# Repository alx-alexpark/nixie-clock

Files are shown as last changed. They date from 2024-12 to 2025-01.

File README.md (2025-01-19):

# ИН-12 Nixie Tube Clock

clock

A nixie tube clock made using ИН-12 (IN-12) tubes. Uses k155id1 drivers and a boost converter made using [this reference design](https://github.com/drkmsmithjr/NixiePowerSupply). Time is synchronized over WiFi using NTP (<1sec inaccuracy), and all firmware is written using CircuitPython.

Read more at https://parkalex.dev/posts/nixieclock

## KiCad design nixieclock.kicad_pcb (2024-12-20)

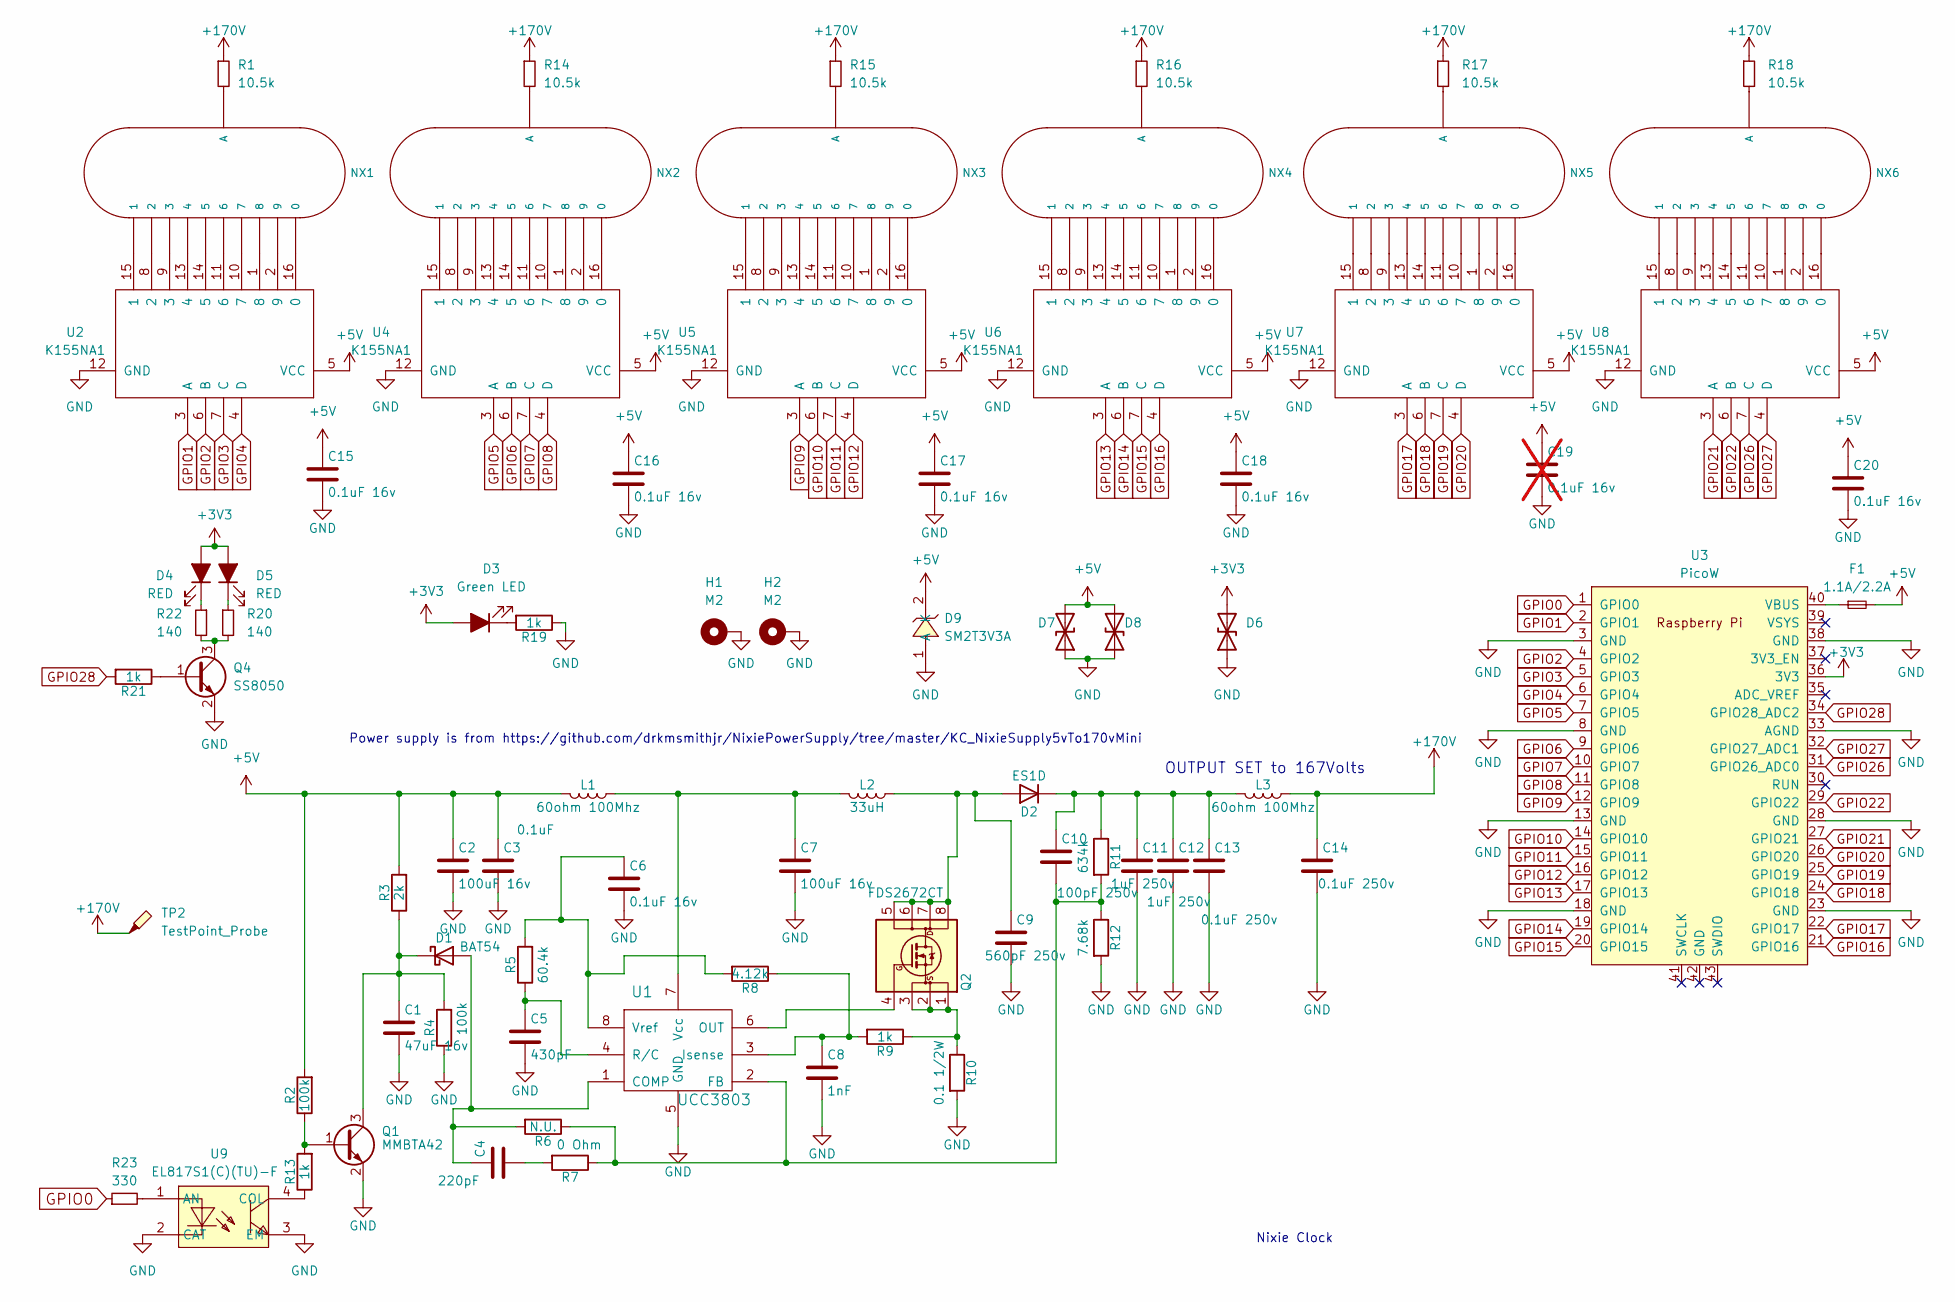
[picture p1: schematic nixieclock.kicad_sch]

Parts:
C1: 47uF 16v; C_1210_3225Metric_Pad1.33x2.70mm_HandSolder; LCSC Part C77101
C2, C7: 100uF 16v; C_1210_3225Metric_Pad1.33x2.70mm_HandSolder; LCSC Part C7432790
C3: 0.1uF; C_0603_1608Metric_Pad1.08x0.95mm_HandSolder; LCSC Part C14663
C4: 220pF; C_0402_1005Metric_Pad0.74x0.62mm_HandSolder; LCSC Part C1530
C5: 430pF; C_0805_2012Metric_Pad1.18x1.45mm_HandSolder; LCSC Part C67898
C6, C15, C16, C17, C18, C20: 0.1uF 16v; C_0603_1608Metric_Pad1.08x0.95mm_HandSolder; LCSC Part C14663
C8: 1nF; C_0603_1608Metric_Pad1.08x0.95mm_HandSolder; LCSC Part C100040
C9: 560pF 250v; C_0805_2012Metric_Pad1.18x1.45mm_HandSolder; LCSC Part C576987
C10: 100pF 250v; C_0805_2012Metric_Pad1.18x1.45mm_HandSolder; LCSC Part C5186766
C11, C12: 1uF 250v; C_1812_4532Metric_Pad1.57x3.40mm_HandSolder; LCSC Part C381468
C13, C14: 0.1uF 250v; C_0805_2012Metric_Pad1.18x1.45mm_HandSolder; LCSC Part C5182461
C19: 0.1uF 16v; C_0603_1608Metric_Pad1.08x0.95mm_HandSolder; LCSC Part C14663; not fitted
D1: BAT54; D_SOD-323_HandSoldering; MPN BAT54WS-7-F; LCSC Part C124205
D2: ES1D; D_SMA_Handsoldering; MPN ES1D; LCSC Part C84602
D3: Green LED; LED_0805_2012Metric_Pad1.15x1.40mm_HandSolder; LCSC Part C2297
D4, D5: RED; LED_0805_2012Metric_Pad1.15x1.40mm_HandSolder; LCSC Part C84256
D6, D7, D8: PESD5V5C1BLYL; D_SOD-882; MPN PESD5V5C1BLYL
D9: SM2T3V3A; DO-216AA_L1.9-W1.9-LS3.8-FD; LCSC Part C970557
F1: 1.1A/2.2A; Fuse_1812_4532Metric_Pad1.30x3.40mm_HandSolder; MPN MF-MSMF110-2
H1, H2: M2; MountingHole_2.2mm_M2_DIN965_Pad_TopBottom
L1, L3: 60ohm 100Mhz; L_0805_2012Metric_Pad1.05x1.20mm_HandSolder; MPN MH2029-600Y
L2: 33uH; WE-PD_1210; MPN 7447709330
NX1, NX2, NX3, NX4, NX5, NX6: IN-12A; nixies-us-IN-12-DSUB
Q1: MMBTA42; SOT-23_Handsoldering; LCSC Part C118745
Q2: FDS2672CT; SOIC-8_3.9x4.9mm_P1.27mm; MPN FDS2672CT-ND
Q4: SS8050; SOT-23
R1, R14, R15, R16, R17, R18: 10.5k; R_0805_2012Metric_Pad1.20x1.40mm_HandSolder; LCSC Part C2093736
R2, R4: 100k; R_0603_1608Metric_Pad0.98x0.95mm_HandSolder; LCSC Part C14675
R3: 2k; R_0603_1608Metric_Pad0.98x0.95mm_HandSolder; LCSC Part C22975
R5: 60.4k; R_0603_1608Metric_Pad0.98x0.95mm_HandSolder; LCSC Part C23089
R6: N.U.
R7: 0 Ohm; R_0603_1608Metric_Pad0.98x0.95mm_HandSolder; LCSC Part C21189
R8: 4.12k; R_0603_1608Metric_Pad0.98x0.95mm_HandSolder; LCSC Part C2960702
R9, R13, R19, R21: 1k; R_0603_1608Metric_Pad0.98x0.95mm_HandSolder; LCSC Part C21190
R10: 0.1 1/2W; C_1210_3225Metric_Pad1.33x2.70mm_HandSolder; LCSC Part C2974119
R11: 634k; R_1206_3216Metric_Pad1.30x1.75mm_HandSolder; LCSC Part C3037408
R12: 7.68k; R_1206_3216Metric_Pad1.30x1.75mm_HandSolder; LCSC Part C3037264
R20, R22: 140; R_0603_1608Metric_Pad0.98x0.95mm_HandSolder; LCSC Part C2974027
R23: 330; R_0603_1608Metric_Pad0.98x0.95mm_HandSolder; LCSC Part C23138
TP2: TestPoint_Probe; TestPoint_Loop_D2.54mm_Drill1.5mm_Beaded
U1: UCC3803; SOIC-8_3.9x4.9mm_P1.27mm; LCSC Part C2657971
U2, U4, U5, U6, U7, U8: K155NA1; DIP-16_W7.62mm_LongPads
U3: PicoW; RPi_PicoW_SMD_TH
U9: EL817S1(C)(TU)-F; OPTO-SMD-4_L4.6-W6.5-P2.54-LS10.3-TL; LCSC Part C106900

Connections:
+3V3: D3.2 (A), D4.2 (A), D5.2 (A), D6.2 (A2), U3.36 (3V3)
+5V: C2.1, C3.1, C15.1, C16.1, C17.1, C18.1, C19.1, C20.1, D7.2 (A2), D8.2 (A2), D9.2 (K), F1.2, L1.2, R2.2, R3.2, U2.5 (VCC), U4.5 (VCC), U5.5 (VCC), U6.5 (VCC), U7.5 (VCC), U8.5 (VCC)
+170V: C14.1, L3.1, R1.1, R14.1, R15.1, R16.1, R17.1, R18.1, TP2.1
GND: C1.2, C2.2, C3.2, C5.2, C6.2, C7.2, C8.2, C9.2, C11.2, C12.2, C13.2, C14.2, C15.2, C16.2, C17.2, C18.2, C19.2, C20.2, D6.1 (A1), D7.1 (A1), D8.1 (A1), D9.1 (A), H1.1, H2.1, Q1.2 (E), Q4.2 (E), R4.1, R10.2, R12.2, R19.1, U1.5 (GND), U2.12 (GND), U3.3 (GND), U3.8 (GND), U3.13 (GND), U3.18 (GND), U3.23 (GND), U3.28 (GND), U3.33 (AGND), U3.38 (GND), U4.12 (GND), U5.12 (GND), U6.12 (GND), U7.12 (GND), U8.12 (GND), U9.2 (CAT), U9.3 (EM)
GPIO0: R23.1, U3.1 (GPIO0)
GPIO1: U2.3 (A), U3.2 (GPIO1)
GPIO2: U2.6 (B), U3.4 (GPIO2)
GPIO3: U2.7 (C), U3.5 (GPIO3)
GPIO4: U2.4 (D), U3.6 (GPIO4)
GPIO5: U3.7 (GPIO5), U4.3 (A)
GPIO6: U3.9 (GPIO6), U4.6 (B)
GPIO7: U3.10 (GPIO7), U4.7 (C)
GPIO8: U3.11 (GPIO8), U4.4 (D)
GPIO9: U3.12 (GPIO9), U5.3 (A)
GPIO10: U3.14 (GPIO10), U5.6 (B)
GPIO11: U3.15 (GPIO11), U5.7 (C)
GPIO12: U3.16 (GPIO12), U5.4 (D)
GPIO13: U3.17 (GPIO13), U6.3 (A)
GPIO14: U3.19 (GPIO14), U6.6 (B)
GPIO15: U3.20 (GPIO15), U6.7 (C)
GPIO16: U3.21 (GPIO16), U6.4 (D)
GPIO17: U3.22 (GPIO17), U7.3 (A)
GPIO18: U3.24 (GPIO18), U7.6 (B)
GPIO19: U3.25 (GPIO19), U7.7 (C)
GPIO20: U3.26 (GPIO20), U7.4 (D)
GPIO21: U3.27 (GPIO21), U8.3 (A)
GPIO22: U3.29 (GPIO22), U8.6 (B)
GPIO26: U3.31 (GPIO26_ADC0), U8.7 (C)
GPIO27: U3.32 (GPIO27_ADC1), U8.4 (D)
GPIO28: R21.2, U3.34 (GPIO28_ADC2)
unnamed: C4.2, R7.2
unnamed: C4.1, D1.2 (A), R6.2, U1.1 (COMP)
unnamed: C1.1, D1.1 (K), Q1.3 (C), R3.1, R4.2
unnamed: C9.1, D2.2 (A), L2.1, Q2.5 (D), Q2.6 (D), Q2.7 (D), Q2.8 (D)
unnamed: C10.1, C11.1, C12.1, C13.1, D2.1 (K), L3.2, R11.1
unnamed: D3.1 (K), R19.2
unnamed: D4.1 (K), R22.1
unnamed: D5.1 (K), R20.1
unnamed: NX1.A, R1.2
unnamed: NX2.A, R14.2
unnamed: NX3.A, R15.2
unnamed: NX4.A, R16.2
unnamed: NX5.A, R17.2
unnamed: NX6.A, R18.2
unnamed: Q1.1 (B), R2.1, R13.2
unnamed: Q2.4 (G), U1.6 (OUT)
unnamed: Q2.1 (S), Q2.2 (S), Q2.3 (S), R9.1, R10.1
unnamed: Q4.1 (B), R21.1
unnamed: Q4.3 (C), R20.2, R22.2
unnamed: C10.2, R6.1, R7.1, R11.2, R12.1, U1.2 (FB)
unnamed: C8.1, R8.1, R9.2, U1.3 (Isense)
unnamed: C5.1, R5.1, U1.4 (R/C)
unnamed: C7.1, L1.1, L2.2, U1.7 (Vcc)
unnamed: C6.1, R5.2, R8.2, U1.8 (Vref)
unnamed: NX1.0, U2.16 (0)
unnamed: NX1.1, U2.15 (1)
unnamed: NX1.2, U2.8 (2)
unnamed: NX1.3, U2.9 (3)
unnamed: NX1.4, U2.13 (4)
unnamed: NX1.5, U2.14 (5)
unnamed: NX1.6, U2.11 (6)
unnamed: NX1.7, U2.10 (7)
unnamed: NX1.8, U2.1 (8)
unnamed: NX1.9, U2.2 (9)
unnamed: F1.1, U3.40 (VBUS)
unnamed: NX2.0, U4.16 (0)
unnamed: NX2.1, U4.15 (1)
unnamed: NX2.2, U4.8 (2)
unnamed: NX2.3, U4.9 (3)
unnamed: NX2.4, U4.13 (4)
unnamed: NX2.5, U4.14 (5)
unnamed: NX2.6, U4.11 (6)
unnamed: NX2.7, U4.10 (7)
unnamed: NX2.8, U4.1 (8)
unnamed: NX2.9, U4.2 (9)
unnamed: NX3.0, U5.16 (0)
unnamed: NX3.1, U5.15 (1)
unnamed: NX3.2, U5.8 (2)
unnamed: NX3.3, U5.9 (3)
unnamed: NX3.4, U5.13 (4)
unnamed: NX3.5, U5.14 (5)
unnamed: NX3.6, U5.11 (6)
unnamed: NX3.7, U5.10 (7)
unnamed: NX3.8, U5.1 (8)
unnamed: NX3.9, U5.2 (9)
unnamed: NX4.0, U6.16 (0)
unnamed: NX4.1, U6.15 (1)
unnamed: NX4.2, U6.8 (2)
unnamed: NX4.3, U6.9 (3)
unnamed: NX4.4, U6.13 (4)
unnamed: NX4.5, U6.14 (5)
unnamed: NX4.6, U6.11 (6)
unnamed: NX4.7, U6.10 (7)
unnamed: NX4.8, U6.1 (8)
unnamed: NX4.9, U6.2 (9)
unnamed: NX5.0, U7.16 (0)
unnamed: NX5.1, U7.15 (1)
unnamed: NX5.2, U7.8 (2)
unnamed: NX5.3, U7.9 (3)
unnamed: NX5.4, U7.13 (4)
unnamed: NX5.5, U7.14 (5)
unnamed: NX5.6, U7.11 (6)
unnamed: NX5.7, U7.10 (7)
unnamed: NX5.8, U7.1 (8)
unnamed: NX5.9, U7.2 (9)
unnamed: NX6.0, U8.16 (0)
unnamed: NX6.1, U8.15 (1)
unnamed: NX6.2, U8.8 (2)
unnamed: NX6.3, U8.9 (3)
unnamed: NX6.4, U8.13 (4)
unnamed: NX6.5, U8.14 (5)
unnamed: NX6.6, U8.11 (6)
unnamed: NX6.7, U8.10 (7)
unnamed: NX6.8, U8.1 (8)
unnamed: NX6.9, U8.2 (9)
unnamed: R23.2, U9.1 (AN)
unnamed: R13.1, U9.4 (COL)

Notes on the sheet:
Power supply is from https://github.com/drkmsmithjr/NixiePowerSupply/tree/master/KC_NixieSupply5vTo170vMini
Nixie Clock
OUTPUT SET to 167Volts

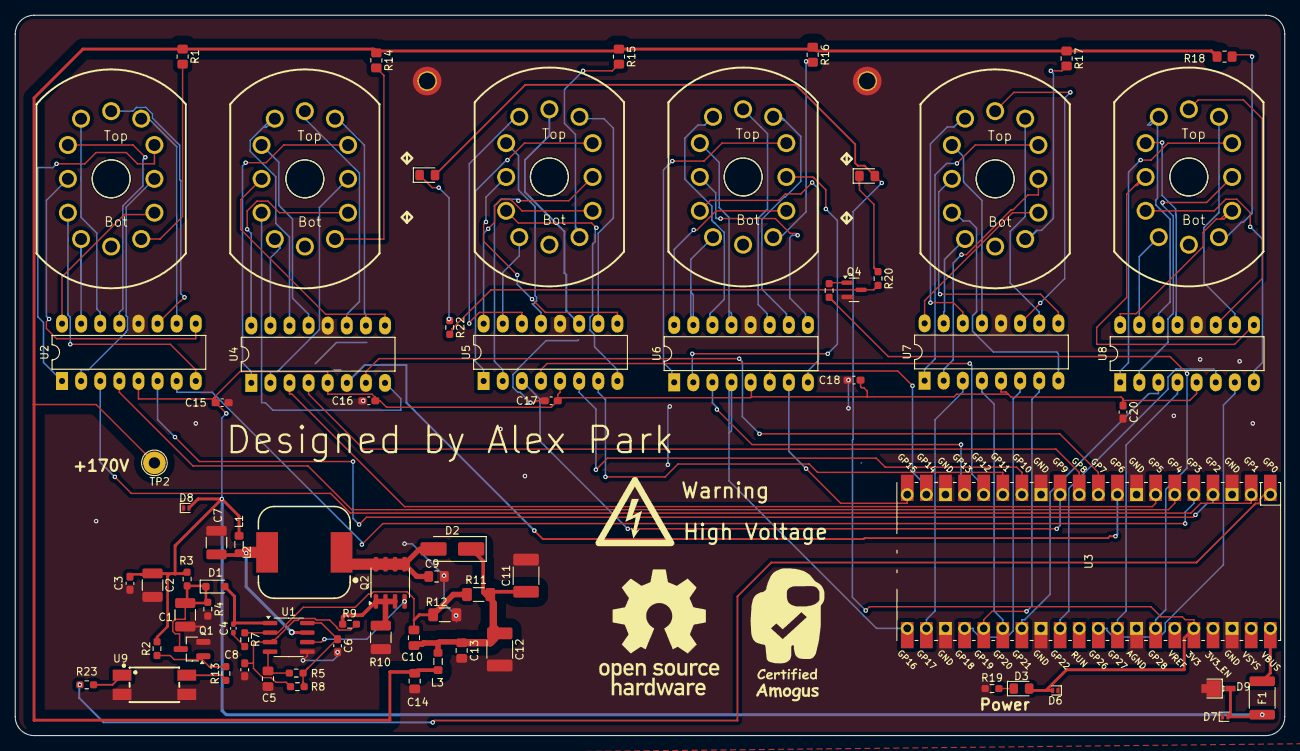
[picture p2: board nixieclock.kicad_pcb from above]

Board: 2 copper layers, 168.8 x 95.8 mm, 75 parts (0 on the bottom side), 117 nets.

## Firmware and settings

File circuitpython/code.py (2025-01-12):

import digitalio
import board

import os
import time

import rtc
import socketpool
import wifi

import adafruit_ntp

HVenable = digitalio.DigitalInOut(board.GP0)
HVenable.direction = digitalio.Direction.OUTPUT

led = digitalio.DigitalInOut(board.GP28)
led.direction = digitalio.Direction.OUTPUT


class NixieTube:
    def __init__(self, pin1, pin2, pin3, pin4):
        self.c1 = digitalio.DigitalInOut(pin1)
        self.c1.direction = digitalio.Direction.OUTPUT
        self.c2 = digitalio.DigitalInOut(pin2)
        self.c2.direction = digitalio.Direction.OUTPUT
        self.c3 = digitalio.DigitalInOut(pin3)
        self.c3.direction = digitalio.Direction.OUTPUT
        self.c4 = digitalio.DigitalInOut(pin4)
        self.c4.direction = digitalio.Direction.OUTPUT
        
        self.c1.value = True
        self.c2.value = True
        self.c3.value = True
        self.c4.value = True

    def display_digit(self, digit):
        # Convert the digit to a 4-bit binary representation
        binary_representation = '{0:04b}'.format(digit)
        print(binary_representation)
        self.c1.value = bool(int(binary_representation[3]))
        self.c2.value = bool(int(binary_representation[2]))
        self.c3.value = bool(int(binary_representation[1]))
        self.c4.value = bool(int(binary_representation[0 ]))


    def clear(self):
        """
        Turn off all segments of the Nixie tube.
        """
        self.c1.value = True
        self.c2.value = True
        self.c3.value = True
        self.c4.value = True
    
nixie1 = NixieTube(board.GP1, board.GP2, board.GP3, board.GP4)
nixie2 = NixieTube(board.GP5, board.GP6, board.GP7, board.GP8)
nixie3 = NixieTube(board.GP9, board.GP10, board.GP11, board.GP12)
nixie4 = NixieTube(board.GP13, board.GP14, board.GP15, board.GP16)
nixie5 = NixieTube(board.GP17, board.GP18, board.GP19, board.GP20)
nixie6 = NixieTube(board.GP21, board.GP22, board.GP26, board.GP27)

wifi_ssid = os.getenv("CIRCUITPY_WIFI_SSID")
wifi_password = os.getenv("CIRCUITPY_WIFI_PASSWORD")
if wifi_ssid is None:
    print("WiFi credentials are kept in settings.toml, please add them there!")
    raise ValueError("SSID not found in environment variables")

try:
    wifi.radio.connect(wifi_ssid, wifi_password)
except ConnectionError:
    print("Failed to connect to WiFi with provided credentials")
    raise

pool = socketpool.SocketPool(wifi.radio)
ntp = adafruit_ntp.NTP(pool, tz_offset=-6, cache_seconds=3600)

rtc.RTC().datetime = ntp.datetime

HVenable.value = True

# After getting the time, do a quick cycle of all the digits to reveal any problems
for digit in range(10):
    led.value = not led.value
    nixie1.display_digit(digit)
    nixie2.display_digit(digit)
    nixie3.display_digit(digit)
    nixie4.display_digit(digit)
    nixie5.display_digit(digit)
    nixie6.display_digit(digit)
    time.sleep(0.3)  
    
nixie1.clear()  
nixie2.clear()
nixie3.clear()
nixie4.clear()
nixie5.clear()
nixie6.clear()

while True:
    print(time.localtime())
    timel = time.localtime()
    
    hour = "{:02}".format(timel.tm_hour)
    min = "{:02}".format(timel.tm_min)
    sec = "{:02}".format(timel.tm_sec)
    
    if timel.tm_sec % 2 == 0:
        led.value = True
    else:
        led.value = False
        
    nixie1.display_digit(int(hour[0]))
    nixie2.display_digit(int(hour[1]))
    nixie3.display_digit(int(min[0]))
    nixie4.display_digit(int(min[1]))
    nixie5.display_digit(int(sec[0]))
    nixie6.display_digit(int(sec[1]))
    
    time.sleep(0.01)

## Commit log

2024-12-15 things happened
    [nixieclock.kicad_pcb, nixieclock.kicad_sch]
2024-12-15 schematic mostly done, started laying out board
    [nixieclock.kicad_pcb, nixieclock.kicad_sch]
2024-12-15 mostly done i guess?
    [nixieclock.kicad_pcb, nixieclock.kicad_sch]
2024-12-16 Finishing touches to pcb
    [nixieclock.kicad_pcb, nixieclock.kicad_sch]
2024-12-16 updates to silk screen
    [nixieclock.kicad_pcb, nixieclock.kicad_sch]
2024-12-17 small modifications to pcb
    [nixieclock.kicad_pcb, nixieclock.kicad_sch]
2024-12-17 more random things
    [nixieclock.kicad_pcb]
2024-12-17 Had the footprints for nixies completely wrong, redid them
    [nixieclock.kicad_pcb, nixieclock.kicad_sch]
2024-12-17 added clearances for safety on hv nets
    [nixieclock.kicad_pcb]
2024-12-18 add tvs diodes for protection
    [nixieclock.kicad_pcb, nixieclock.kicad_sch]
2024-12-18 increase board size
    [nixieclock.kicad_pcb, nixieclock.kicad_sch]
2024-12-20 final order
    [nixieclock.kicad_pcb, nixieclock.kicad_sch]
